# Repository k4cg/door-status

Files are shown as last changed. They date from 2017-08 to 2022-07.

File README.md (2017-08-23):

# K4CG door-status

This program submits the k4cg space door status to "heimat". It is intended to run on an ESP8266 controller with micropython firmware. In the "hardware" directory, you can find a case design for OpenSCAD, which is suitable for 3D-printing.

[Link: Miropython ESP8266 Docs](http://docs.micropython.org/en/latest/esp8266/)

## Status Transmission

The data transfer is periodically performed by the ESP (~ 5 minute intervals) to http://heimat:8000 via PUT request.

It contains a JSON formatted structure like:
```
{"humidity": 35, "door": "open", "date": "2017-08-21 19:11:50", "tempDoor": 27}
```

## Code Upload

First time upload: Connect via serial port with mpfshell:

```
# mpfshell -c "open ttyUSB0"
mpfs [/]> put boot.py
mpfs [/]> put service.py
...
```

Update code:
```
# mpfshell -c "open ws:192.168.178.9,PASSWORD"
mpfs [/]> put boot.py
mpfs [/]> put service.py
...
mpfs [/]> repl
>>> reboot()
```

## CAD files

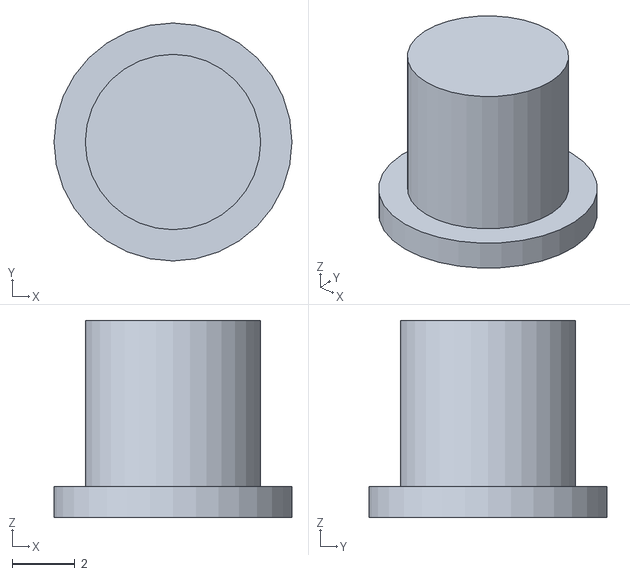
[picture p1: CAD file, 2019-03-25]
sensor/doorsensor-top.stl
7.60 x 7.60 x 6.30

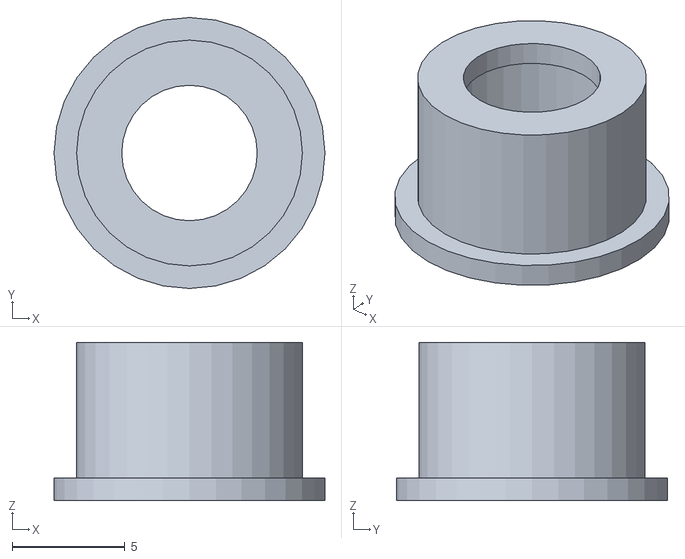
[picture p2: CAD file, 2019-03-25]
sensor/doorsensor-bottom.stl
12.0 x 12.0 x 7.00

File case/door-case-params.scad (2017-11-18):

/*	
	k4cg door-status
	Copyright (C) 2017  Christian Carlowitz <chca@cmesh.de>

	This program is free software: you can redistribute it and/or modify
	it under the terms of the GNU General Public License as published by
	the Free Software Foundation, either version 3 of the License, or
	(at your option) any later version.

	This program is distributed in the hope that it will be useful,
	but WITHOUT ANY WARRANTY; without even the implied warranty of
	MERCHANTABILITY or FITNESS FOR A PARTICULAR PURPOSE.  See the
	GNU General Public License for more details.

	You should have received a copy of the GNU General Public License
	along with this program.  If not, see <http://www.gnu.org/licenses/>.
*/

eps = 0.1;
$fn=32;

boardGap = 1;
boardX = 65+eps; // PCB width
boardY = 65+eps; // PCB depth
boardZ = 0; // PCB height
addZ = 23; // additional Y height until top part begins
wall = 1.4; // casing wall thickness
wallInsetW = 0;
wallInsetH = 0;
wallInsetOff = 0.2;

bottomHeight = 1.4;

mountR = 3;
mountW = 7;
mountHeight = boardZ+addZ;
mountDrill = 2.5;
mountHole = 3;

screwSinkH = 2.5;
screwSinkD = 6.5;

// top plate
topHeight = 3.5;

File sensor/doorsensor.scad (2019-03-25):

$fn=32;

wall=1;
inner=8;
H=6;
eps=0.1;
offs=0.4;
Hi=13.3-H-2*wall;

color("blue",0.5)
difference()
{
	union()
	{
		cylinder(h=H+wall,d=inner+2*wall);
		cylinder(h=wall,d=12);
	}
	translate([0,0,-eps])
	cylinder(h=H+eps,d=inner);
	
	cylinder(h=20,d=inner-2*wall);
}

*color("red",0.5)
translate([0,0,H-wall])
difference()
{
	union()
	{
		cylinder(h=Hi+wall,d=inner-2*wall-offs);
		cylinder(h=wall,d=inner-offs);
	}
	translate([0,0,-eps])
	cylinder(h=Hi+eps,d=inner-4*wall+offs);
}

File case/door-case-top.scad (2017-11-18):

/*	
	k4cg door-status
	Copyright (C) 2017  Christian Carlowitz <chca@cmesh.de>

	This program is free software: you can redistribute it and/or modify
	it under the terms of the GNU General Public License as published by
	the Free Software Foundation, either version 3 of the License, or
	(at your option) any later version.

	This program is distributed in the hope that it will be useful,
	but WITHOUT ANY WARRANTY; without even the implied warranty of
	MERCHANTABILITY or FITNESS FOR A PARTICULAR PURPOSE.  See the
	GNU General Public License for more details.

	You should have received a copy of the GNU General Public License
	along with this program.  If not, see <http://www.gnu.org/licenses/>.
*/

// *** all dimensions in mm ***

include <door-case-params.scad>

module shell(w,x,y,z,winw,winh,woff)
{
	union()
	{
		difference()
		{
			cube([x+w, y+w, z]); // outer volume
	
			//translate([-eps,-eps,-eps])
			//cube([x+winw+woff+eps,y+winw+woff+eps,winh*2+2*eps]); // notch
		}
		
		//cube([x-woff*3,y-woff*3,z-eps]);
	}
}

module case()
{
	difference()
	{
		union()
		{
			// outer case shell
			shell(wall, boardX/2+boardGap, boardY/2+boardGap, topHeight,
				wallInsetW, wallInsetH, wallInsetOff);
		}

		translate([boardX/2-mountR, boardY/2-mountR, -eps])
		{
			// screw drill
			cylinder(h=(topHeight+2*eps), r=mountHole/2);
			
			// screw sink
			translate([0,0,topHeight-screwSinkH+eps])
			cylinder(h=(screwSinkH+eps), r=screwSinkD/2);
		}
	}
}

module cut(x,y,w,h)
{
	translate([x-w/2,y-h/2,-eps])
	cube([w,h,topHeight+2*eps]);
}

module body()
{

	union()
	{
		difference()
		{
			union()
			{
				translate([-eps,-eps,0])
				case();

				mirror([-1,0,0])
				translate([-eps,-eps,0])
				case();

				mirror([0,-1,0])
				translate([-eps,-eps,0])
				case();

				mirror([0,-1,0])
				mirror([-1,0,0])
				translate([-eps,-eps,0])
				case();
			}

			cut(22,10,1.5,20);
			cut(18,10,1.5,20);
			cut(14,10,1.5,20);
			cut(10,10,1.5,20);

		}
	}
}

module fillet(r,l) // along y axis
{
	translate([0,-l/2-eps,0])
	difference()
	{
		cube([r*2,l+2*eps,r*2]);
		translate([0,-eps,0])
		rotate([-90,0,0])
		cylinder(h=l+4*eps,r=r);
	}
}

filletR = 2;
caseY = boardY+2*boardGap+2*wall-2*eps; // -2*eps: remove offset for union of mirrored parts
caseX = boardX+2*boardGap+2*wall-2*eps;

difference()
{
	body();

	translate([caseX/2-filletR,0,topHeight-filletR])
	fillet(filletR,caseY);

	rotate([0,0,180])
	translate([caseX/2-filletR,0,topHeight-filletR])
	fillet(filletR,caseY);
	
	translate([0,caseY/2-filletR,topHeight-filletR])
	rotate([0,0,90])
	fillet(filletR,caseX);

	rotate([0,0,180])
	translate([0,caseY/2-filletR,topHeight-filletR])
	rotate([0,0,90])
	fillet(filletR,caseX);
}

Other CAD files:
case/door-case.scad

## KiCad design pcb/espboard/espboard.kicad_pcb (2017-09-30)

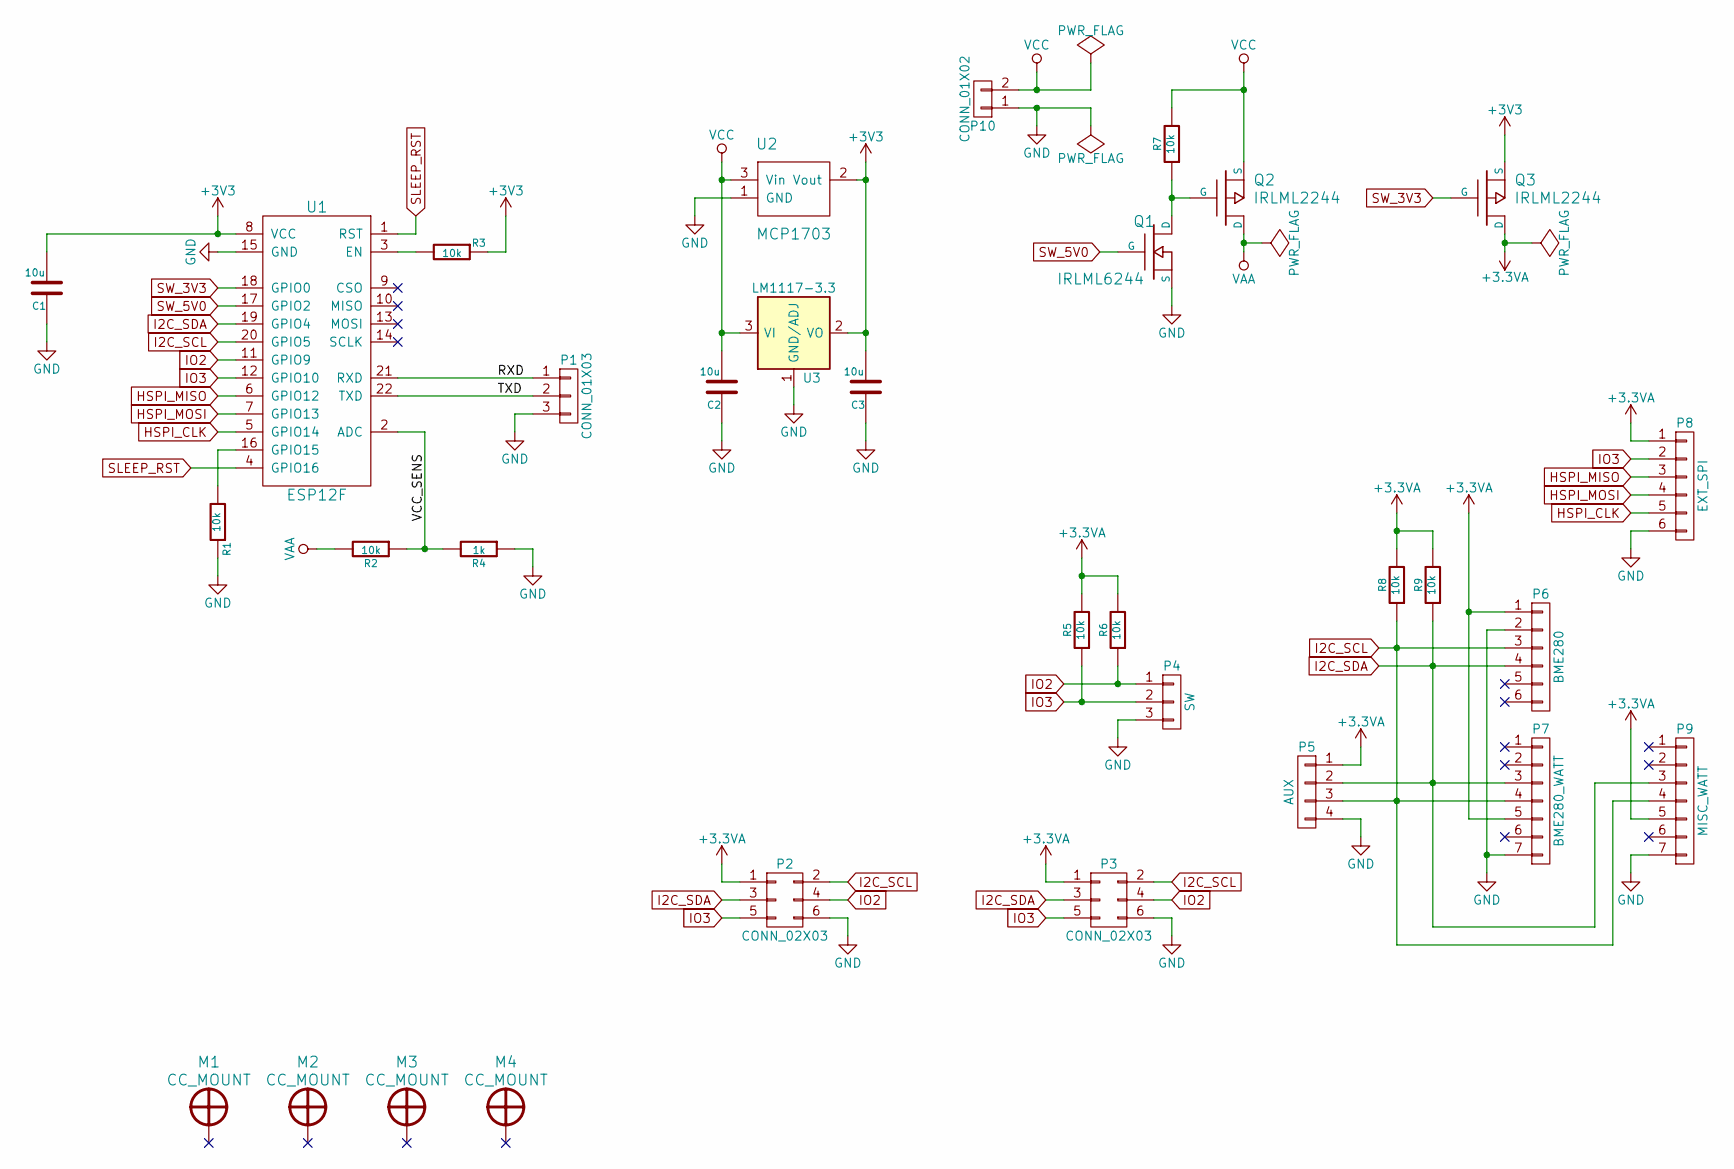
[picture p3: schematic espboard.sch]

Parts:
C1, C2, C3: 10u; rcl-cc-0402
M1, M2, M3, M4: CC_MOUNT; CC_MOUNT_PLATED_M3
P1: CONN_01X03; Pin_Header_Straight_1x03_Pitch2.54mm
P2, P3: CONN_02X03; con-harting-ml-ML6
P4: SW; Pin_Header_Straight_1x03_Pitch2.54mm
P5: AUX; Pin_Header_Straight_1x04_Pitch2.54mm
P6: BME280; Pin_Header_Straight_1x06_Pitch2.54mm
P7: BME280_WATT; Pin_Header_Straight_1x07_Pitch2.54mm
P8: EXT_SPI; Pin_Header_Straight_1x06_Pitch2.54mm
P9: MISC_WATT; Pin_Header_Straight_1x07_Pitch2.54mm
P10: CONN_01X02; Pin_Header_Straight_1x02_Pitch2.54mm
Q1: IRLML6244; CC_SOT23_MOS1
Q2, Q3: IRLML2244; CC_SOT23_MOS1
R1, R2, R3, R5, R6, R7, R8, R9: 10k; rcl-cc-0402
R4: 1k; rcl-cc-0402
U1: ESP12F; esp12f
U2: MCP1703; SOT-89-3_Handsoldering
U3: LM1117-3.3; SOT-223

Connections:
+3.3VA: P2.1, P3.1, P5.1, P6.1, P7.5, P8.1, P9.5, Q3.D, R5.2, R6.2, R8.2, R9.2
+3V3: C1.2, C3.2, Q3.S, R3.1, U1.8 (VCC), U2.2 (Vout), U3.2 (VO), U3.4 (VO)
/RXD: P1.1, U1.21 (RXD)
/TXD: P1.2, U1.22 (TXD)
/VCC_SENS: R2.1, R4.2, U1.2 (ADC)
GND: C1.1, C2.1, C3.1, P1.3, P2.6, P3.6, P4.3, P5.4, P6.2, P7.7, P8.6, P9.7, P10.1, Q1.S, R1.1, R4.1, U1.15 (GND), U2.1 (GND), U3.1 (GND/ADJ)
HSPI_CLK: P8.5, U1.5 (GPIO14)
HSPI_MISO: P8.3, U1.6 (GPIO12)
HSPI_MOSI: P8.4, U1.7 (GPIO13)
I2C_SCL: P2.2, P3.2, P5.3, P6.3, P7.4, P9.4, R8.1, U1.20 (GPIO5)
I2C_SDA: P2.3, P3.3, P5.2, P6.4, P7.3, P9.3, R9.1, U1.19 (GPIO4)
IO2: P2.4, P3.4, P4.1, R6.1, U1.11 (GPIO9)
IO3: P2.5, P3.5, P4.2, P8.2, R5.1, U1.12 (GPIO10)
unnamed: Q1.D, Q2.G, R7.1
unnamed: R1.2, U1.16 (GPIO15)
unnamed: R3.2, U1.3 (EN)
SLEEP_RST: U1.1 (RST), U1.4 (GPIO16)
SW_3V3: Q3.G, U1.18 (GPIO0)
SW_5V0: Q1.G, U1.17 (GPIO2)
VAA: Q2.D, R2.2
VCC: C2.2, P10.2, Q2.S, R7.2, U2.3 (Vin), U3.3 (VI)

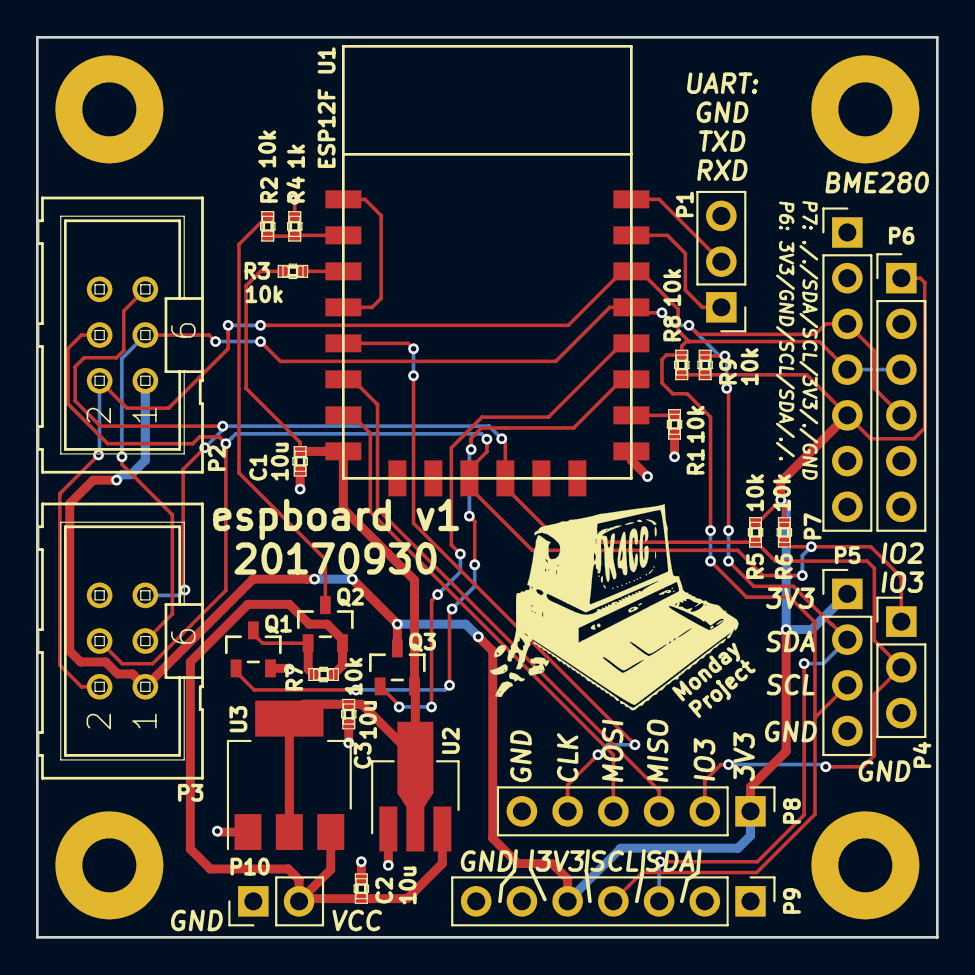
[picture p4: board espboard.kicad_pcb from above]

Board: 2 copper layers, 50.0 x 50.0 mm, 32 parts (0 on the bottom side), 21 nets.

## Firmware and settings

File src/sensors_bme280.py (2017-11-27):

# Authors: Paul Cunnane 2016, Peter Dahlebrg 2016
#
# This module borrows from the Adafruit BME280 Python library. Original
# Copyright notices are reproduced below.
#
# Those libraries were written for the Raspberry Pi. This modification is
# intended for the MicroPython and esp8266 boards.
#
# Copyright (c) 2014 Adafruit Industries
# Author: Tony DiCola
#
# Based on the BMP280 driver with BME280 changes provided by
# David J Taylor, Edinburgh (www.satsignal.eu)
#
# Based on Adafruit_I2C.py created by Kevin Townsend.
#
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
import time
from ustruct import unpack, unpack_from
from array import array

# BME280 default address.
BME280_I2CADDR = 0x76

# Operating Modes
BME280_OSAMPLE_1 = 1
BME280_OSAMPLE_2 = 2
BME280_OSAMPLE_4 = 3
BME280_OSAMPLE_8 = 4
BME280_OSAMPLE_16 = 5

BME280_REGISTER_CONTROL_HUM = 0xF2
BME280_REGISTER_CONTROL = 0xF4


class BME280:

	def __init__(self,
				 mode=BME280_OSAMPLE_1,
				 address=BME280_I2CADDR,
				 i2c=None,
				 **kwargs):
		# Check that mode is valid.
		if mode not in [BME280_OSAMPLE_1, BME280_OSAMPLE_2, BME280_OSAMPLE_4,
						BME280_OSAMPLE_8, BME280_OSAMPLE_16]:
			raise ValueError(
				'Unexpected mode value {0}. Set mode to one of '
				'BME280_ULTRALOWPOWER, BME280_STANDARD, BME280_HIGHRES, or '
				'BME280_ULTRAHIGHRES'.format(mode))
		self._mode = mode
		self.address = address
		if i2c is None:
			raise ValueError('An I2C object is required.')
		self.i2c = i2c

		# load calibration data
		dig_88_a1 = self.i2c.readfrom_mem(self.address, 0x88, 26)
		dig_e1_e7 = self.i2c.readfrom_mem(self.address, 0xE1, 7)
		self.dig_T1, self.dig_T2, self.dig_T3, self.dig_P1, \
			self.dig_P2, self.dig_P3, self.dig_P4, self.dig_P5, \
			self.dig_P6, self.dig_P7, self.dig_P8, self.dig_P9, \
			_, self.dig_H1 = unpack("<HhhHhhhhhhhhBB", dig_88_a1)

		self.dig_H2, self.dig_H3 = unpack("<hB", dig_e1_e7)
		e4_sign = unpack_from("<b", dig_e1_e7, 3)[0]
		self.dig_H4 = (e4_sign << 4) | (dig_e1_e7[4] & 0xF)

		e6_sign = unpack_from("<b", dig_e1_e7, 5)[0]
		self.dig_H5 = (e6_sign << 4) | (dig_e1_e7[4] >> 4)

		self.dig_H6 = unpack_from("<b", dig_e1_e7, 6)[0]

		self.i2c.writeto_mem(self.address, BME280_REGISTER_CONTROL,
							 bytearray([0x3F]))
		self.t_fine = 0

		# temporary data holders which stay allocated
		self._l1_barray = bytearray(1)
		self._l8_barray = bytearray(8)
		self._l3_resultarray = array("i", [0, 0, 0])

	def read_raw_data(self, result):
		""" Reads the raw (uncompensated) data from the sensor.

			Args:
				result: array of length 3 or alike where the result will be
				stored, in temperature, pressure, humidity order
			Returns:
				None
		"""

		self._l1_barray[0] = self._mode
		self.i2c.writeto_mem(self.address, BME280_REGISTER_CONTROL_HUM,
							 self._l1_barray)
		self._l1_barray[0] = self._mode << 5 | self._mode << 2 | 1
		self.i2c.writeto_mem(self.address, BME280_REGISTER_CONTROL,
							 self._l1_barray)

		sleep_time = 1250 + 2300 * (1 << self._mode)
		sleep_time = sleep_time + 2300 * (1 << self._mode) + 575
		sleep_time = sleep_time + 2300 * (1 << self._mode) + 575
		time.sleep_us(sleep_time)  # Wait the required time

		# burst readout from 0xF7 to 0xFE, recommended by datasheet
		self.i2c.readfrom_mem_into(self.address, 0xF7, self._l8_barray)
		readout = self._l8_barray
		# pressure(0xF7): ((msb << 16) | (lsb << 8) | xlsb) >> 4
		raw_press = ((readout[0] << 16) | (readout[1] << 8) | readout[2]) >> 4
		# temperature(0xFA): ((msb << 16) | (lsb << 8) | xlsb) >> 4
		raw_temp = ((readout[3] << 16) | (readout[4] << 8) | readout[5]) >> 4
		# humidity(0xFD): (msb << 8) | lsb
		raw_hum = (readout[6] << 8) | readout[7]

		result[0] = raw_temp
		result[1] = raw_press
		result[2] = raw_hum

	def read_compensated_data(self, result=None):
		""" Reads the data from the sensor and returns the compensated data.

			Args:
				result: array of length 3 or alike where the result will be
				stored, in temperature, pressure, humidity order. You may use
				this to read out the sensor without allocating heap memory

			Returns:
				array with temperature, pressure, humidity. Will be the one from
				the result parameter if not None
		"""
		self.read_raw_data(self._l3_resultarray)
		raw_temp, raw_press, raw_hum = self._l3_resultarray
		# temperature
		var1 = ((raw_temp >> 3) - (self.dig_T1 << 1)) * (self.dig_T2 >> 11)
		var2 = (((((raw_temp >> 4) - self.dig_T1) *
				  ((raw_temp >> 4) - self.dig_T1)) >> 12) * self.dig_T3) >> 14
		self.t_fine = var1 + var2
		temp = (self.t_fine * 5 + 128) >> 8

		# pressure
		var1 = self.t_fine - 128000
		var2 = var1 * var1 * self.dig_P6
		var2 = var2 + ((var1 * self.dig_P5) << 17)
		var2 = var2 + (self.dig_P4 << 35)
		var1 = (((var1 * var1 * self.dig_P3) >> 8) +
				((var1 * self.dig_P2) << 12))
		var1 = (((1 << 47) + var1) * self.dig_P1) >> 33
		if var1 == 0:
			pressure = 0
		else:
			p = 1048576 - raw_press
			p = (((p << 31) - var2) * 3125) // var1
			var1 = (self.dig_P9 * (p >> 13) * (p >> 13)) >> 25
			var2 = (self.dig_P8 * p) >> 19
			pressure = ((p + var1 + var2) >> 8) + (self.dig_P7 << 4)

		# humidity
		h = self.t_fine - 76800
		h = (((((raw_hum << 14) - (self.dig_H4 << 20) -
				(self.dig_H5 * h)) + 16384)
			  >> 15) * (((((((h * self.dig_H6) >> 10) *
							(((h * self.dig_H3) >> 11) + 32768)) >> 10) +
						  2097152) * self.dig_H2 + 8192) >> 14))
		h = h - (((((h >> 15) * (h >> 15)) >> 7) * self.dig_H1) >> 4)
		h = 0 if h < 0 else h
		h = 419430400 if h > 419430400 else h
		humidity = h >> 12

		if result:
			result[0] = temp
			result[1] = pressure
			result[2] = humidity
			return result

		return array("i", (temp, pressure, humidity))

	@property
	def values(self):
		""" human readable values """

		t, p, h = self.read_compensated_data()

		p = p // 256
		pi = p // 100
		pd = p - pi * 100

		hi = h // 1024
		hd = h * 100 // 1024 - hi * 100
		return ("{}C".format(t / 100), "{}.{:02d}hPa".format(pi, pd),
				"{}.{:02d}%".format(hi, hd))

	@property
	def fvalues(self):
		t, p, h = self.read_compensated_data()
		t = t / 100
		p = (p // 256) / 100
		h = h / 1024
		return (t,p,h)

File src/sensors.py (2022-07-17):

#	
#	k4cg door-status
#	Copyright (C) 2017  Christian Carlowitz <chca@cmesh.de>
#
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

import dht
import machine
import time

def power(pwr3v3=False, pwr5v0=False):
	pin3v3 = machine.Pin(0, machine.Pin.OUT)
	pin5v0 = machine.Pin(2, machine.Pin.OUT)
	
	if pwr3v3:
		pin3v3.value(0)
	else:
		pin3v3.value(1)
		
	if pwr5v0:
		pin5v0.value(1)
	else:
		pin5v0.value(0)

class Door:
	def __init__(self):
		pass
	
	def read(self):
		sw = machine.Pin(12, machine.Pin.IN, machine.Pin.PULL_UP)
		time.sleep(0.2)
		v = sw.value() == 1
		sw = machine.Pin(12, machine.Pin.IN, None)
		return v
		
	def json(self):
		v = self.read()
		stat = "open" if v else "closed"
		return {"status": stat, "statusBool": v}

class BME280:
	def __init__(self, i2c, addr):
		from sensors_bme280 import BME280 as BME280_dev
		self.bme = BME280_dev(address = addr, i2c = i2c)
	
	def read(self):
		self.temp, self.press, self.humi = self.bme.fvalues
		return (self.temp, self.press, self.humi)
		
	def json(self):
		self.read()
		self.read()
		return { 
			"bme280/temperature" : float("%.2f" % self.temp),
			"bme280/pressure" : float("%.2f" % self.press),
			"bme280/humidity" : float("%.2f" % self.humi),
		}

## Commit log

2017-08-23 added openscad files for case 3d printing, updated and fixed readme
    [door-case-params.scad, door-case-top.scad, door-case.scad]
2017-09-09 added watchdog timer, moved some timing values to json config
2017-09-11 use internal pullup for door switch
2017-09-14 fixed bug in door status setting
    [service.py]
2017-09-30 moved case to 'case' folder
    [door-case-params.scad, door-case-top.scad, door-case.scad]
2017-09-30 added pcb
    [espboard-B.Cu.gbr, espboard-B.Mask.gbr, espboard-B.SilkS.gbr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]
2017-11-18 updated case for pcb
    [door-case-params.scad, door-case-top.scad, door-case.scad]
2017-11-27 added power config, added i2c and bme280
2017-11-27 implemented service handling for sensor config lists
2017-12-07 make http push less critical, fixed bug
    [service.py]
2019-03-25 added p5 sensor mechanism
    [doorsensor-bottom.stl, doorsensor-top.stl, doorsensor.scad]

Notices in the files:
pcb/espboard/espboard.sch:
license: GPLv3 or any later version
